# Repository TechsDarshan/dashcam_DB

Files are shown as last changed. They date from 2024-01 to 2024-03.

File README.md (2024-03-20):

# Dashcam Daughter board(DDB)

The Dashcam Daughter Board is a sub-board of the Dashcam project. It controls the neopixel indicators, includes a buzzer, and houses a reset button.

## Connection:

At Daughter Board:
| JST- DDB | Jetson Nano |
|--|--|
| +5v | +5v |
|LED Selector|GPIO15|
| ValuePin_1|GPIO16|
|ValuePin_2|GPIO18|
|Push button |GPIO19|
|Buzzer|GPIO20|
|NC||
|GND|GND|

# Code Building:

## Attiny85 is flashed with neo.ino

Use the 6 pin ISP programming port to flash/change the code.

##LED Controller library can be called to control the state LEDs 1 & 2.

### Installation

To use the LED Controller library in your project, simply include the `ledcontroller.py` file in your project directory.

### Usage

Import the `ledcontroller` module in your Python script to gain access to the `setcolor()` function. Use this function to control the state of LEDs 1 and 2 by specifying the LED index and desired color.

### Functionality

#### `setcolor(index, color)`

Set the color of the specified LED.

- `index`: 0 for LED 1, 1 for LED 2.
- `color`: Available options - NONE, RED, GREEN, ORANGE.

### Example code

````python
from LEDController import LEDController
  import time
  print("Starting demo now! Press CTRL+C to exit")
  leds = LEDController()
  for led in (0, 1):
    for color in LEDController.COLORS:
      print('Setting LED {} to {}'.format(led, color))
      leds.setColor(led, color)
      time.sleep(1)
      ```
````

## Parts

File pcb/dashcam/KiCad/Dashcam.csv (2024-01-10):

Reference | Value | Footprint | Qty | Procurment
BZ1 | Buzzer | Buzzer_Beeper:Buzzer_12x9.5RM7.6 | 1 | Roland,local
C1, C5-C8 | 100nF | Capacitor_SMD:C_0603_1608Metric | 5 | bgtronics,local
DC_U1, DC_U4 | 100nF | Capacitor_SMD:C_0603_1608Metric | 2 | bgtronics,local
FID1-FID4 | Fiducial | Fiducial:Fiducial_1mm_Mask2mm | 4 | -
J3 | Conn_02x03_Odd_Even | Connector_PinHeader_1.00mm:PinHeader_2x03_P1.00mm_Vertical | 1 | -
J4 | Conn_01x08_Pin | Connector_JST:JST_GH_BM08B-GHS-TBT_1x08-1MP_P1.25mm_Vertical | 1 | sunrom | 8 pin SMD JST 1.25mm Top Entry Header [6202] : Sunrom Electronics
R1, R3, R5 | 10k | Resistor_SMD:R_0603_1608Metric | 3 | bgtronics,local
R2 | 0E | Resistor_SMD:R_0603_1608Metric | 1 | bgtronics,local
R4 | 1k | Resistor_SMD:R_0603_1608Metric | 1 | bgtronics,local
R6-R9 | 470R | Resistor_SMD:R_0603_1608Metric | 4 | bgtronics,local
SW1 | SW_Push | Button_Switch_SMD:SW_SPST_B3U-3000P | 1 | mouser | B3U-3000P Omron Electronics | Mouser India
U1, U4 | WS2812B | LED_SMD:LED_WS2812B_PLCC4_5.0x5.0mm_P3.2mm | 2 | mouser | COM-16346 SparkFun | Mouser India
U2 | BC547 | Package_TO_SOT_SMD:SOT-23 | 1 | robu | BC547 SMD Transistor (Pack of 20) - Robu.in | Indian Online Store | RC Hobby | Robotics
U3 | ATTINY85-20SU | ATTINY85-20SU:SOIC127P798X216-8N | 1 | mouser | ATTINY85-20SU Microchip Technology | Mouser India

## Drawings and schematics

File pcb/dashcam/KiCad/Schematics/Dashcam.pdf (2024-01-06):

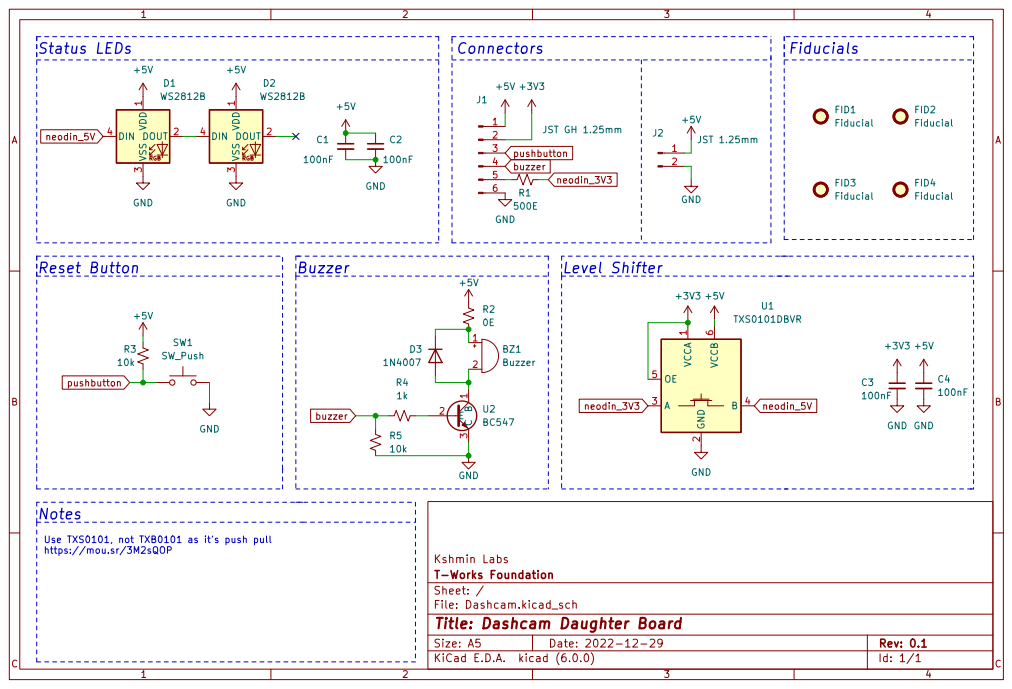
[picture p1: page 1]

Use TXS0101, not TXB0101 as it's push pull
https://mou.sr/3M2sQOP

Id: 1/1 Title: Dashcam Daughter Board

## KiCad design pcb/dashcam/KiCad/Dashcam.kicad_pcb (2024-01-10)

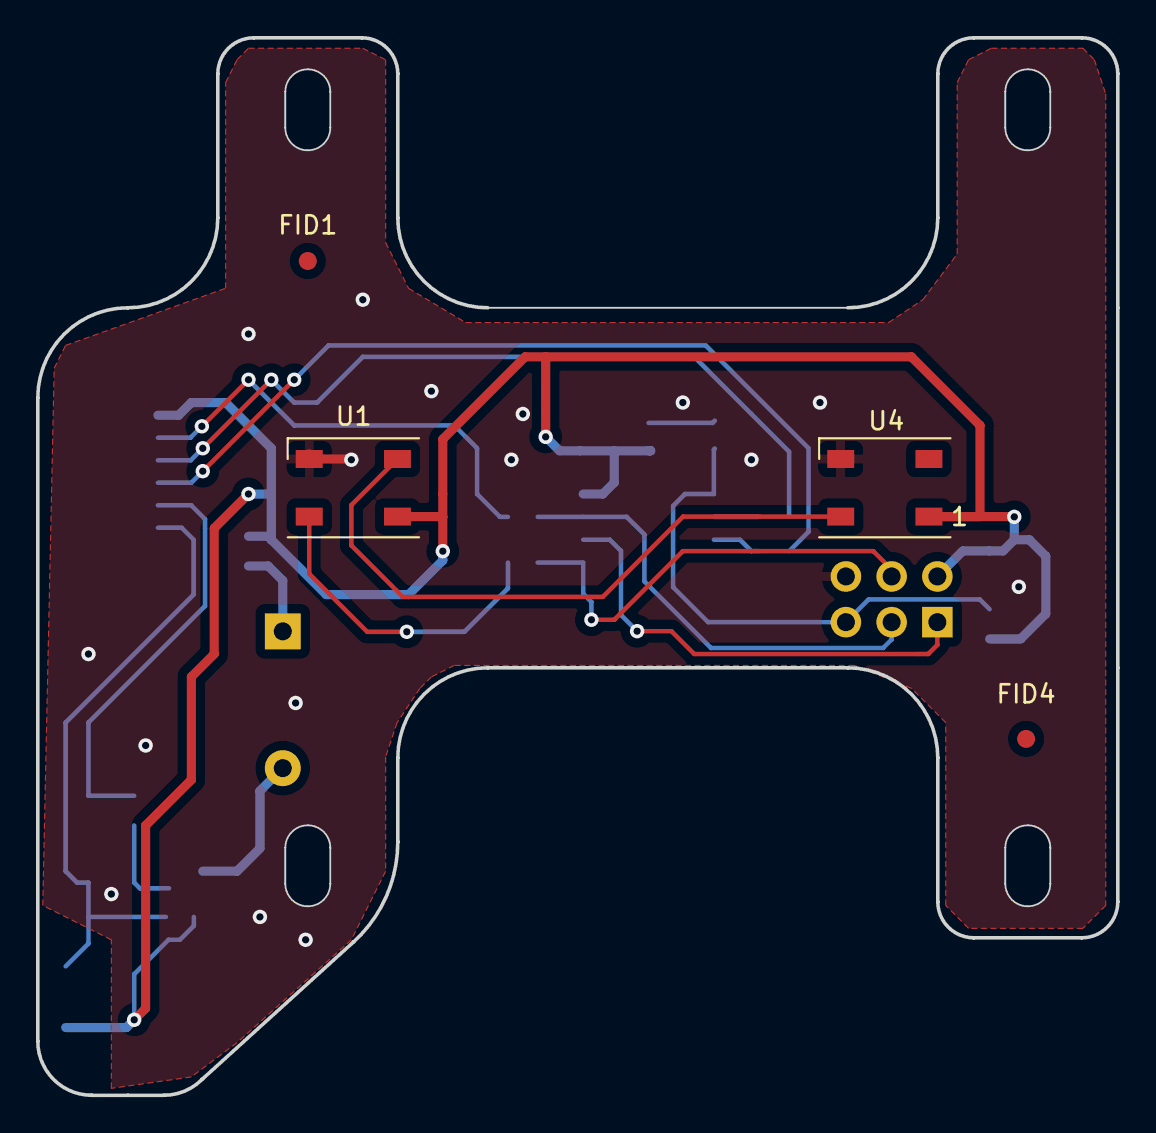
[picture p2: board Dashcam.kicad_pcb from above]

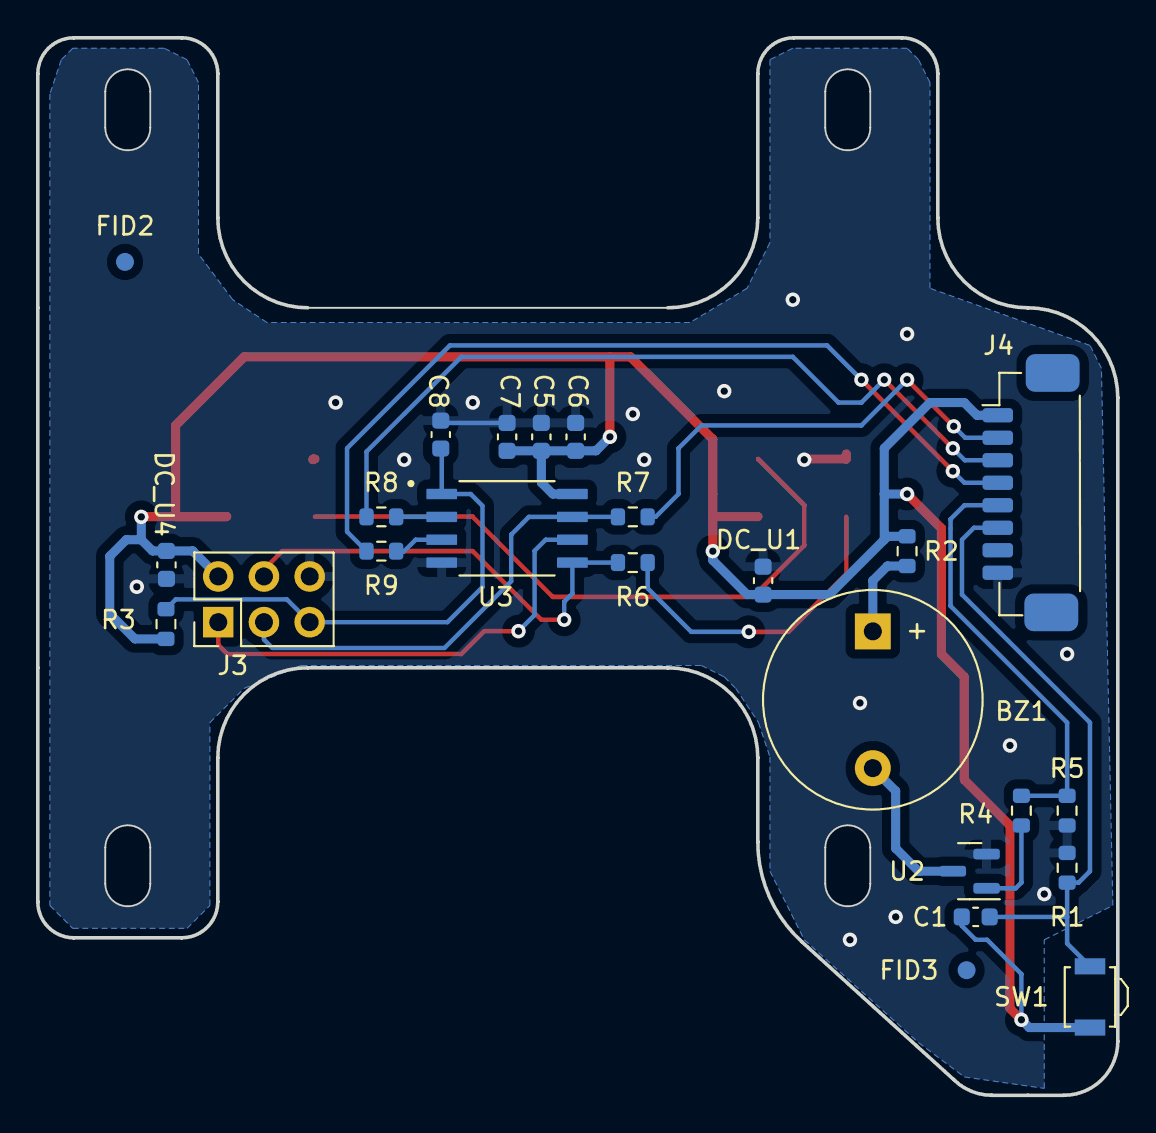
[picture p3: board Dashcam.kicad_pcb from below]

Board: 2 copper layers, 60.0 x 58.8 mm, 28 parts (24 on the bottom side), 18 nets.

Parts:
BZ1: Buzzer; Buzzer_12x9.5RM7.6
C1, C5, C6, C7, C8: 100nF; C_0603_1608Metric
DC_U1, DC_U4: 100nF; C_0603_1608Metric
FID1, FID2, FID3, FID4: Fiducial; Fiducial_1mm_Mask2mm
J3: Conn_02x03_Odd_Even; PinHeader_2x03_P2.54mm_Vertical
J4: Conn_01x08_Pin; JST_GH_BM08B-GHS-TBT_1x08-1MP_P1.25mm_Vertical
R1, R3, R5: 10k; R_0603_1608Metric
R2: 0E; R_0603_1608Metric
R4: 1k; R_0603_1608Metric
R6, R7, R8, R9: 470R; R_0603_1608Metric
SW1: SW_Push; SW_SPST_B3U-3000P
U1, U4: WS2812B; LED_WS2812B_PLCC4_5.0x5.0mm_P3.2mm
U2: BC547; SOT-23
U3: ATTINY85-20SU; SOIC127P798X216-8N

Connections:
+5V: C1.1, C5.2, C6.2, C7.2, DC_U1.1, DC_U4.1, J3.2, J4.1, R2.1, R3.2, SW1.2, U1.1 (VDD), U3.8 (VCC), U4.1 (VDD)
GND: C5.1, C6.1, C7.1, C8.1, DC_U1.2, DC_U4.2, J3.6, J4.8, R1.2, R5.1, U1.3 (VSS), U2.2 (E), U3.4 (GND), U4.3 (VSS)
LED Selector: J4.2, R7.1
MISO: J3.1, U3.6 (PB1)
MOSI: J3.4, R6.2, U3.5 (PB0)
unnamed: BZ1.2 (+), U2.3 (C)
unnamed: BZ1.1 (-), R2.2
unnamed: U1.2 (DOUT), U4.4 (DIN)
unnamed: R4.2, U2.1 (B)
unnamed: R8.1, U3.2 (PB3)
unnamed: R9.1, U3.3 (PB4)
Reset: C8.2, J3.5, R3.1, U3.1 (PB5)
SEK: J3.3, R7.2, U3.7 (PB2)
ValuePin_1: J4.3, R8.2
ValuePin_2: J4.4, R9.2
buzzer: J4.5, R4.1, R5.2
neodin: R6.1, U1.4 (DIN)
pushbutton: C1.2, J4.6, R1.1, SW1.1

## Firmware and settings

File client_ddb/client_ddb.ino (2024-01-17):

#include <Adafruit_NeoPixel.h>

#include "SoftwareSerial.h"
#ifdef __AVR__
#include <avr/power.h> // Required for 16 MHz Adafruit Trinket
#endif

#define LED_SELECTOR 2
#define INPUT1 3
#define INPUT2 4
#define NUM_PIXELS 2
#define OUTPUT_PIN 0

Adafruit_NeoPixel pixels(NUM_PIXELS, OUTPUT_PIN, NEO_GRB + NEO_KHZ800);
const int colors[4][3] = {{0, 0, 0}, {255, 0, 0}, {0, 255, 0}, {255, 165, 0}};

void setup() {
#if defined(__AVR_ATtiny85__) && (F_CPU == 8000000)
  clock_prescale_set(clock_div_1);
#endif
  pinMode(LED_SELECTOR, INPUT);
  pinMode(INPUT1, INPUT);
  pinMode(INPUT2, INPUT);
  pinMode(OUTPUT_PIN, OUTPUT);
  pixels.begin();
  pixels.clear();
  pixels.setBrightness(100);
}

void loop() {
  const int led = digitalRead(LED_SELECTOR);
  const int(&color)[3] = colors[digitalRead(INPUT2) << 1 | digitalRead(INPUT1)];
  pixels.setPixelColor(led, color[0], color[1], color[2]);
  pixels.show();
}

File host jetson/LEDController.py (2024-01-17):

#!/usr/bin/python3
import time

import Jetson.GPIO as GPIO


class LEDController:
    COLORS = {
        "NONE": (GPIO.LOW, GPIO.LOW),
        "RED": (GPIO.LOW, GPIO.HIGH),
        "GREEN": (GPIO.HIGH, GPIO.LOW),
        "ORANGE": (GPIO.HIGH, GPIO.HIGH),
    }

    def __init__(self):
        self.value_pins = [16, 18]
        self.selector_pin = 15
        GPIO.setmode(GPIO.BOARD)
        for pin in (15, 16, 18):
            GPIO.setup(pin, GPIO.OUT, initial=GPIO.LOW)

    def setColor(self, index, color):
        """Set color of the led.
        index = 0 or 1 - to specify the LED whose color should be set.
        color = one of ('NONE', 'RED', 'GREEN', '   ORANGE')"""
        if color in LEDController.COLORS and index in (0, 1):
            values = LEDController.COLORS[color]
            GPIO.output(self.selector_pin, index)
            for i in range(len(self.value_pins)):
                GPIO.output(self.value_pins[i], values[i])
            return True
        return False

    def __del__(self):
        try:
            # FIXME: This is throwing error: name 'open' is not defined in python3
            GPIO.cleanup()
        except:
            pass


if __name__ == "__main__":
    import time

    print("   Starting demo now! Press CTRL+C to exit")
    leds = LEDController()
    for led in (0, 1):
        for color in LEDController.COLORS:
            print("Setting LED {} to {}".format(led, color))
            leds.setColor(led, color)
            time.sleep(1)

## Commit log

2024-01-08 diode removed added cap to push reset ckt
    [Dashcam.kicad_pcb, Dashcam.kicad_sch]
2024-01-09 pcb- pulldown removed, 470 ohm added in series
    [Dashcam.kicad_pcb, Dashcam.kicad_sch]
2024-01-10 added gerber files and changed 2x3 connector
    [Dashcam-B_Cu.gbr, Dashcam-B_Mask.gbr, Dashcam-B_Paste.gbr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]
